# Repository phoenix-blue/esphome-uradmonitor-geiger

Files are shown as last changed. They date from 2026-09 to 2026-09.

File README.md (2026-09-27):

# ESPHome Geiger Counter with Home Assistant and uRADMonitor

ESPHome firmware for a NodeMCU V3 (ESP8266) connected to a RadiationD v1.1
CAJOE Geiger counter board. The ESP counts pulses locally, exposes measurements
and diagnostics to Home Assistant, and can upload CPM readings directly to
uRADMonitor without requiring Home Assistant or MQTT for the upload path.

This is an independent community project and is not affiliated with
uRADMonitor or ESPHome.

Dutch project page: [Help het stralingsmeetnetwerk uitbreiden](https://phoenix-blue.github.io/esphome-uradmonitor-geiger/)

## Features

- Counts active-low Geiger pulses on `D1` / `GPIO5`.
- Publishes CPM, total pulses, and a five-minute CPM average to Home Assistant.
- Uploads uRADMonitor EXP fields `01` (Unix time) and `0B` (CPM).
- Keeps `Off`, `Test`, and `Production` modes strictly separate.
- Stores separate test and production Device IDs in ESP8266 flash.
- Defaults to `Off` on first use and later restores the deliberately selected mode.
- Registers a Device ID only after `Test` or `Production` is deliberately selected.
- Exposes upload results, counters, active Device ID, uptime, Wi-Fi signal,
  free heap, largest heap block, fragmentation, and reset reason.
- Includes a dependency-free Python mock server and a Docker Compose setup.
- Includes a compact snap-fit enclosure as final, print-ready STL files.

The implementation uses normal ESPHome YAML packages and lambdas. No custom
C++ component or external ESPHome library is required.

## Hardware and electrical safety

The reference setup uses:

- NodeMCU V3 / ESP8266
- RadiationD v1.1 CAJOE Geiger counter board
- Pulse output connected to `D1` (`GPIO5`)
- A shared ground between both boards

ESP8266 GPIO pins are **not 5 V tolerant**. Some Geiger boards and clones have
different output stages, so measure the pulse output before connecting it. If
the pulse can reach 5 V, use a level shifter or a resistor divider. A commonly
used divider is 10 kΩ from the signal to `D1` and 15 kΩ from `D1` to ground,
which reduces 5 V to approximately 3 V.

Do not connect two independent 5 V supplies to the NodeMCU at the same time
unless the power arrangement explicitly prevents back-feeding.

## Printable enclosure

A compact enclosure is included for this measured hardware combination. It
keeps the Geiger board and ESP8266 inline, preserves access to the Geiger
board's barrel-power input, and closes with a snap-fit lid.

The current compact v7 base and lid are provided as print-ready STL files.
Editable STEP files are intentionally not included.

> The PCB models in the CAD images are simplified dimensional models for
> enclosure documentation, not manufacturing-accurate replicas.

### Printed concept enclosure

This photo shows the current printed concept version. The PCBs are still
secured with screws in this prototype. A newer enclosure revision is being
developed with improved snap-in PCB mounting.

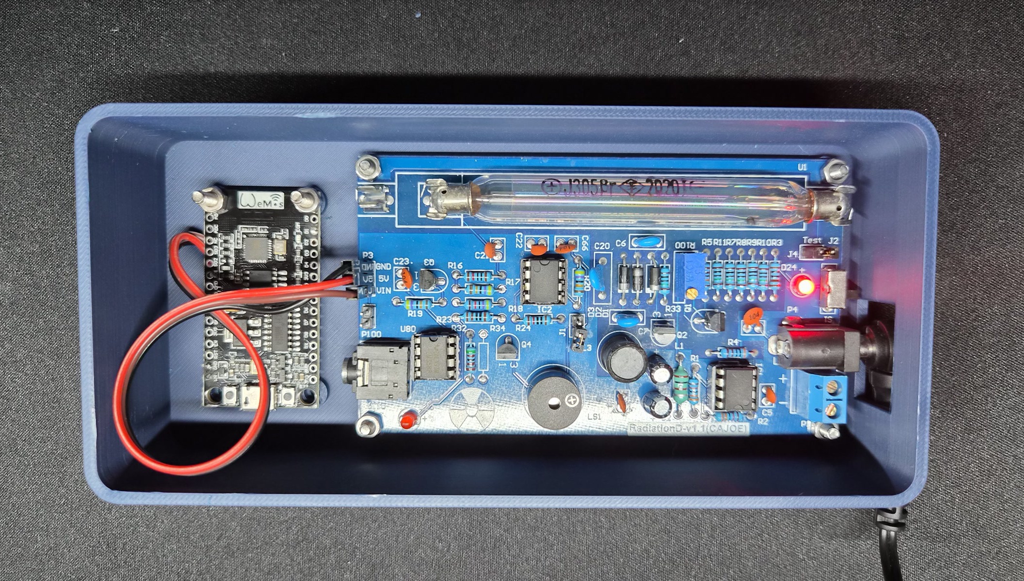
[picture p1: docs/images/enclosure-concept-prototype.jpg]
Printed concept enclosure


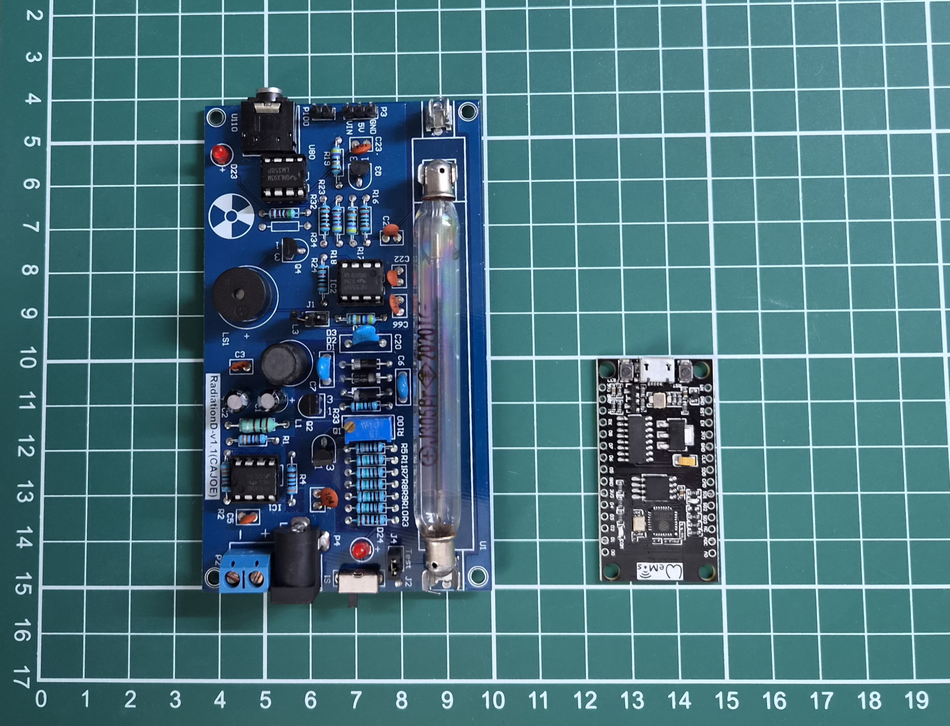
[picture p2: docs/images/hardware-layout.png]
Reference hardware layout


| Closed enclosure | Open enclosure |
| --- | --- |
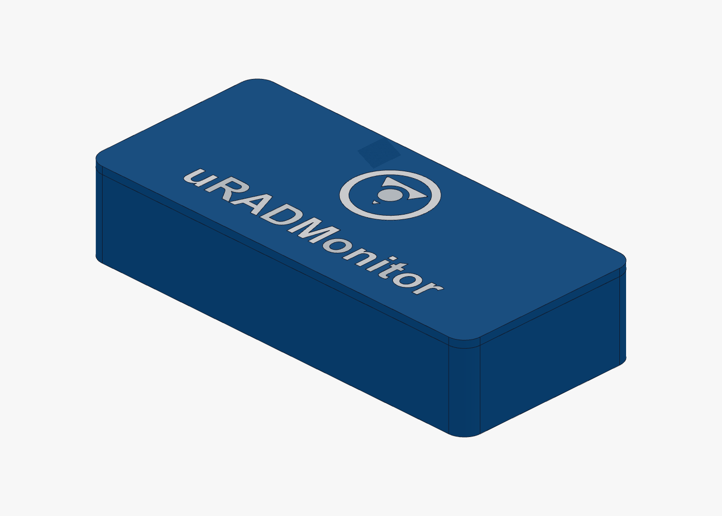
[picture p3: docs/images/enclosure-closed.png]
Closed enclosure render
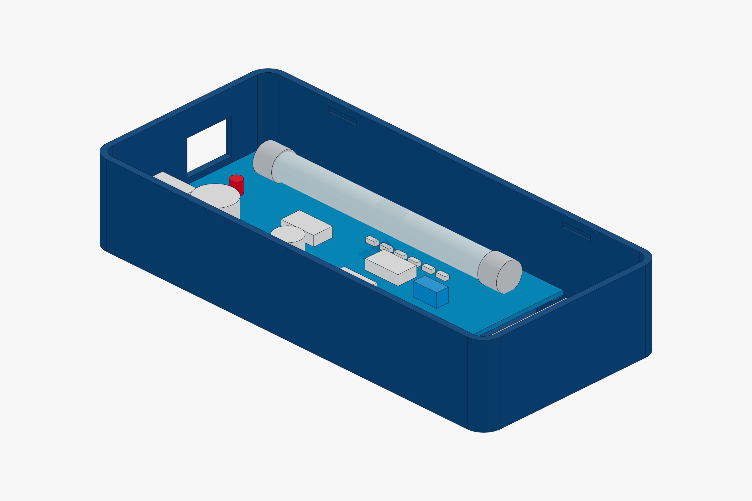
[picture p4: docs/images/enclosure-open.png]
Open enclosure with simplified PCB models
|  |  |
| Exploded view | Lid raised |
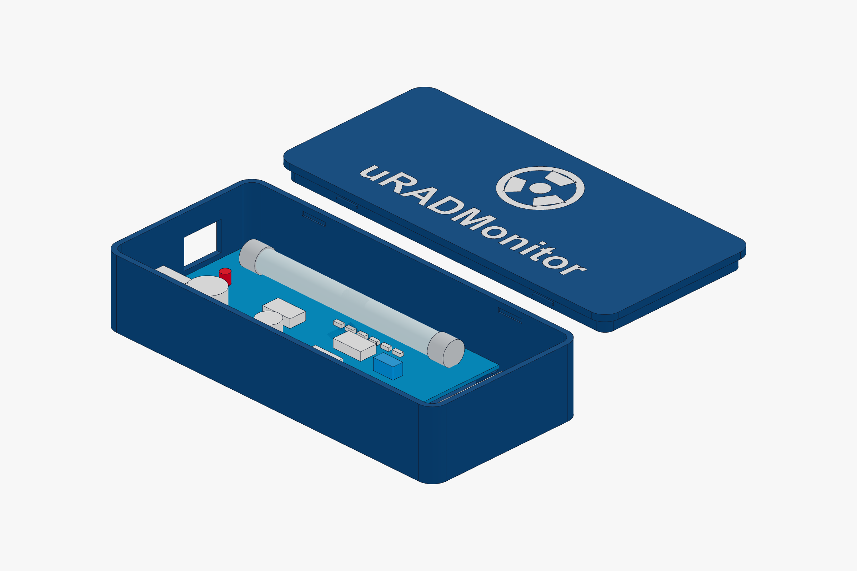
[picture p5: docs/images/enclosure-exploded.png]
Exploded enclosure render
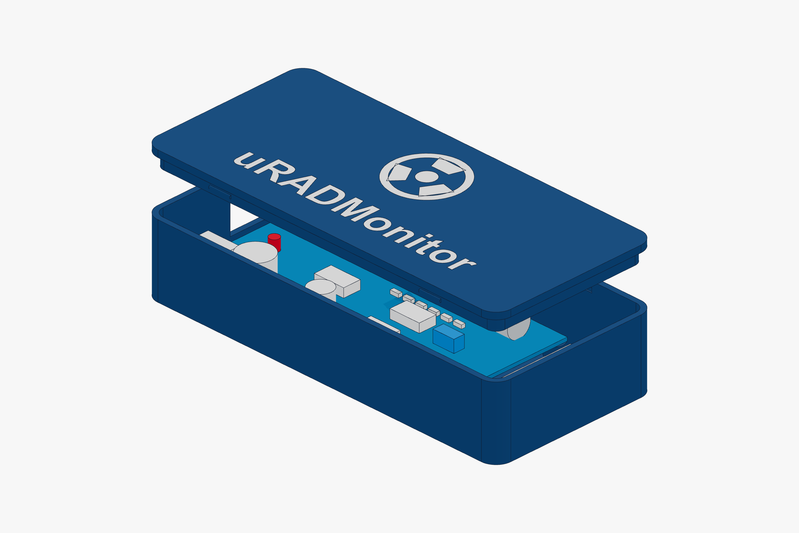
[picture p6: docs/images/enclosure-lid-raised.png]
Enclosure with the lid raised
|  |  |

## Repository layout

| Path | Purpose |
| --- | --- |
| `geiger_node.yaml` | Complete example device configuration |
| `packages/geiger_core.yaml` | Pulse counter and ESP8266 diagnostics |
| `packages/urad_upload.yaml` | Registration, modes, and uploader |
| `secrets.example.yaml` | Safe template for local credentials |
| `mock/urad_mock.py` | Local uRADMonitor-compatible test endpoint |
| `mock/compose.yaml` | Optional Docker Compose deployment |
| `hardware/enclosure/` | Compact v7 base/lid STL files |
| `docs/images/` | Reference photo and enclosure renders |

## Installation

### Option 1: use the complete example

1. Clone or download this repository into your ESPHome configuration directory.
2. Copy `secrets.example.yaml` to `secrets.yaml`.
3. Replace every placeholder in `secrets.yaml`.
4. Confirm `geiger_pin`, board type, and wiring in `geiger_node.yaml`.
5. Validate, compile, and install:

```bash
esphome config geiger_node.yaml
esphome compile geiger_node.yaml
esphome run geiger_node.yaml
```

Keep the directory structure intact because `geiger_node.yaml` includes both
files from `packages/`.

### Option 2: include the packages from GitHub

Add the following to your own device YAML:

```yaml
packages:
  geiger_uradmonitor:
    url: https://github.com/phoenix-blue/esphome-uradmonitor-geiger
    ref: main
    refresh: 1d
    files:
      - packages/geiger_core.yaml
      - packages/urad_upload.yaml
```

Remote ESPHome packages cannot look up secrets from the remote repository.
Define the required substitutions in your local YAML before including them:

```yaml
substitutions:
  geiger_pin: GPIO5
  upload_interval: 60s
  urad_upload_url: https://data.uradmonitor.com/api/v1/upload/exp/
  urad_mock_url: !secret urad_mock_url
  urad_user_id: !secret urad_user_id
  urad_user_hash: !secret urad_user_hash
```

Your local configuration must also provide an SNTP time component with the ID
`sntp_time`, plus `http_request`, `api`, Wi-Fi, and the other platform settings
shown in `geiger_node.yaml`.

See the official [ESPHome packages documentation](https://esphome.io/components/packages/)
for package syntax and merge behavior.

## Secrets and credentials

| Secret | Where to obtain or generate it |
| --- | --- |
| `wifi_ssid`, `wifi_password` | Your local Wi-Fi configuration |
| `api_encryption_key` | Generate with `openssl rand -base64 32` |
| `ota_password` | Choose a unique local OTA password |
| `fallback_ap_password` | Choose a unique fallback access-point password |
| `web_username`, `web_password` | Choose local credentials for the device web UI |
| `urad_mock_url` | Address of the included mock server |
| `urad_user_id`, `urad_user_hash` | API tab in your uRADMonitor account |

Never commit `secrets.yaml`. It is ignored by `.gitignore`. If a real key or
password is ever committed or shared, rotate it; removing it from the latest
file does not remove it from Git history.

## Safe first run

1. Install the firmware while the upload mode remains `Off`.
2. Confirm that CPM changes in Home Assistant when the counter detects pulses.
3. Start the local mock server and set the mode to `Test`.
4. Confirm automatic registration and successful test uploads.
5. Only then select `Production` to register and upload to uRADMonitor.

Test and production Device IDs are stored independently. A Device ID returned
by the mock server is therefore never reused for production.

## Local mock server

Run it directly:

```bash
cd mock
python3 urad_mock.py
```

Or use Docker Compose:

```bash
cd mock
docker compose up --build -d
```

Default endpoints:

- Health: `http://SERVER_IP:8080/health`
- Status and recent requests: `http://SERVER_IP:8080/status`
- Upload: `http://SERVER_IP:8080/api/v1/upload/exp/`

The defaults are intentionally test-only: user ID `test`, hash `test`, and
returned Device ID `13ABC001`. They can be changed with the environment
variables documented at the top of `mock/urad_mock.py`.

The mock validates authentication, registration, monotonically increasing
timestamps, field `01`, and numeric field `0B`. It can also inject delay or
periodic failures for resilience testing.

## uRADMonitor protocol behavior

Production requests use the account credentials in `X-User-id` and
`X-User-hash`, and the assigned sensor identifier in `X-Device-id`. A device
without an assigned ID first registers with reserved Device ID `13000000` and
stores the returned `setid`. Uploads then send:

- `01`: current Unix timestamp
- `0B`: current CPM

This proof of concept deliberately sends only these two fields. The
uRADMonitor dashboard currently exposes additional channels for the registered
device even though no values for those fields are uploaded; this is under
investigation.

Refer to the official
[uRADMonitor open-data upload tutorial](https://www.uradmonitor.com/open-data-upload-tutorial/)
for account setup, headers, registration, and field definitions.

The production endpoint is encoded in the URL path because that form was
confirmed against the live service. The local mock uses the documented request
body form, making both behaviors easy to inspect without sending test data to
the public service.

## Home Assistant entities

The native ESPHome API exposes:

- Radiation CPM, total pulses, and five-minute average
- uRAD upload mode, active Device ID, latest result, and latest response
- Successful and failed upload counters
- Manual upload and test-ID reset buttons
- Uptime and Wi-Fi signal
- Free heap, largest free block, heap fragmentation, and reset reason

No production registration-reset button is exposed. This avoids accidentally
creating a new public device identity from the Home Assistant UI.

## ESP8266 HTTPS note

`verify_ssl: false` is deliberate. ESPHome does not support certificate
verification for `http_request` on ESP8266. The 16,384-byte receive buffer is
also deliberate because modern HTTPS servers can use TLS records of that size.
Both HTTPS and the built-in web server consume scarce ESP8266 memory, which is
why the diagnostic entities are included.

See the official
[ESPHome HTTP Request documentation](https://esphome.io/components/http_request/)
for the current platform limitations and TLS buffer guidance.

## Extending the sensor

A DS18B20 temperature probe can be added through ESPHome's OneWire components.
Supply voltage can also be measured with the ESP8266 ADC, but only through a
properly calculated divider that keeps the board's A0 input within its allowed
range. Other spare environmental sensors may be added later, but each channel
should be validated locally and against the uRADMonitor field definitions
before production upload is enabled. Validate memory stability before adding
these features.

## License

MIT — see [LICENSE](LICENSE).

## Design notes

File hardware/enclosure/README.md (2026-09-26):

# Printable enclosure

This directory contains the current compact v7 print files:

- `cajoe_geiger_esp_v7_base.stl`
- `cajoe_geiger_esp_v7_lid.stl`

The lid is currently supplied as a single-colour STL model. Editable STEP
source files are intentionally not published.

## Reference geometry

- Enclosure outside dimensions: approximately 160 × 75 × 35 mm
- Geiger PCB: approximately 126 × 63 mm
- Geiger PCB mounting-hole pitch: approximately 101.2 × 56.8 mm
- Base mounting holes: 3.3 mm diameter
- ESP8266 board: approximately 58 × 25 mm
- ESP8266 mounting-hole pitch: 43 × 21 mm
- ESP8266 mounting holes: 3.8 mm diameter
- Barrel connector centre: 18 mm from the adjacent Geiger PCB mounting-hole centre

The ESP8266 is rotated 90 degrees and positioned inline with the Geiger PCB to
keep the enclosure compact. The lid uses a snap fit.

## Printing

- Print the base with its floor on the build plate.
- Print the lid with its outside face on the build plate when your printer can
  reproduce the raised lettering cleanly; otherwise rotate it to suit your
  preferred finish and support strategy.
- A 0.20 mm layer height and at least three walls are sensible starting points.
- PLA and PETG are both suitable for an indoor enclosure.
- Test the snap fit and barrel-connector clearance before final assembly.

Dimensions are based on one measured board revision. Confirm critical
clearances if your Geiger or ESP8266 board is a different clone or revision.

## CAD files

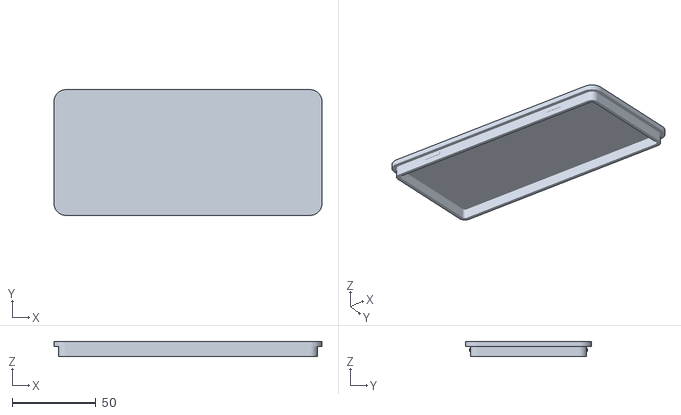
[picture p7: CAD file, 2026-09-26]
hardware/enclosure/cajoe_geiger_esp_v7_lid.stl
160.0 x 75.0 x 9.00

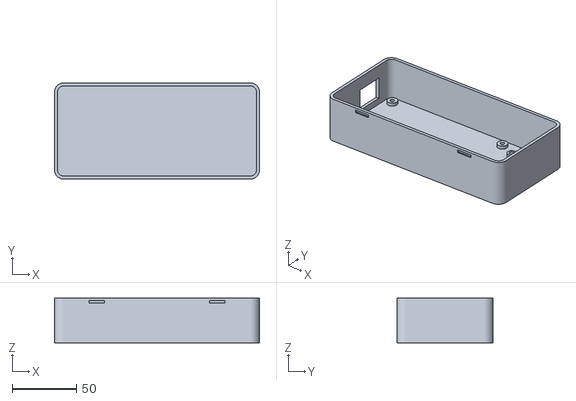
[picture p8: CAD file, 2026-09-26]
hardware/enclosure/cajoe_geiger_esp_v7_base.stl
160.0 x 75.0 x 35.0

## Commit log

2026-09-25 Add printable Geiger enclosure and Bambu 3MFs
    [geiger_enclosure_base.step, geiger_enclosure_base.stl, geiger_enclosure_base_18mm.3mf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]
2026-09-25 Fix lid logo placement on outside face
    [geiger_enclosure_lid_multicolor.3mf]
2026-09-25 Fix overlapping multicolor lid geometry
    [geiger_enclosure_lid_multicolor.3mf]
2026-09-25 Remove enclosure files from public repository
    [geiger_enclosure_base.step, geiger_enclosure_base.stl, geiger_enclosure_base_18mm.3mf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]
2026-09-25 Add printable enclosure STL files and documentation
    [geiger_enclosure_compact_v2_base.stl, geiger_enclosure_compact_v2_lid.stl]
2026-09-26 Add compact v7 enclosure print files
    [cajoe_geiger_esp_v7_base.stl, cajoe_geiger_esp_v7_lid.stl, cajoe_geiger_esp_v7_lid_2color_bambu.3mf]
2026-09-26 Remove unfinished 3MF enclosure file
    [cajoe_geiger_esp_v7_lid_2color_bambu.3mf]
2026-09-26 Add Dutch uRADMonitor project landing page
2026-09-26 Add printed enclosure concept update
2026-09-27 Improve enclosure concept image
